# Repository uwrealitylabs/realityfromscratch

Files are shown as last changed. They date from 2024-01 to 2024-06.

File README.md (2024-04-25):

## Overview

We are building our very own, fully custom VR headset called **Reality from Scratch**.

First, we soldered an inertial measurement unit (IMU) and microcontroller unit (MCU) together, and got real-time motion vector data translated into SteamVR with drivers forked from the OpenVR SDK. Then, the VR Compositor output was routed to our VR displays, which comes with accompanying lenses and a custom 3D-printed housing. In addition to the HMD, we are building Vive Wand-style controllers, which we'll dive into deeper below.

From this headset, we plan to build other systems, such as an inside-out 6DoF tracking solution using visual-inertial odometry, or a varifocal optical stack using eye tracking and motors or voice coils.

<div align="middle">
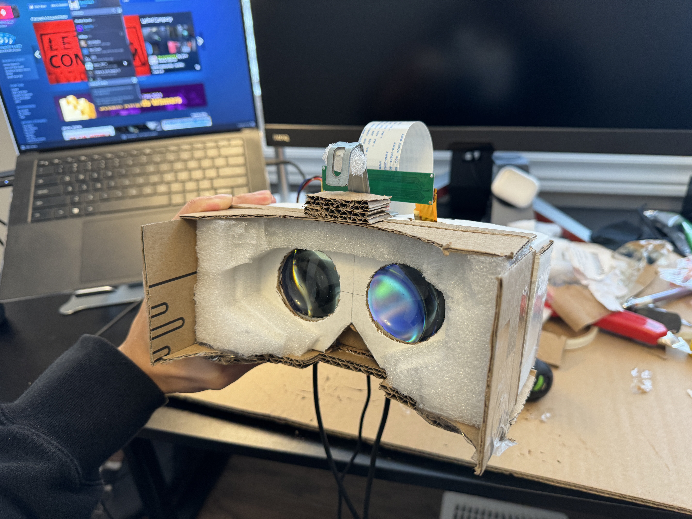
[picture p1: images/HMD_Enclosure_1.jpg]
HMD Enclosure for the HMD
 </div>

### Basic HMD Hardware

| **Components** | **Our Choice** | **Count** |
| --- | --- | --- |
| IMU | MPU-9250 | 1 |
| MCU | Arduino Pro Micro | 1 |
| Display | 1440x1440 90Hz LCDs | 2 |
| Housing | 3D-printed | *varies* |
| Lenses | $⌀=50mm,$ $f = 50mm$, biconvex, glass | 2 |

### 6DoF Tracking Hardware

| **Components** | **Count** |
| --- | --- |
| PS3 Eye Camera | min 1, max 7 |
| HadesVR/PS3 Move Controllers | 2 |
| USB Hubs | *varies* |

Here's a simple flow chart of how the different components of the VR device interact with each other:

<div align="middle">
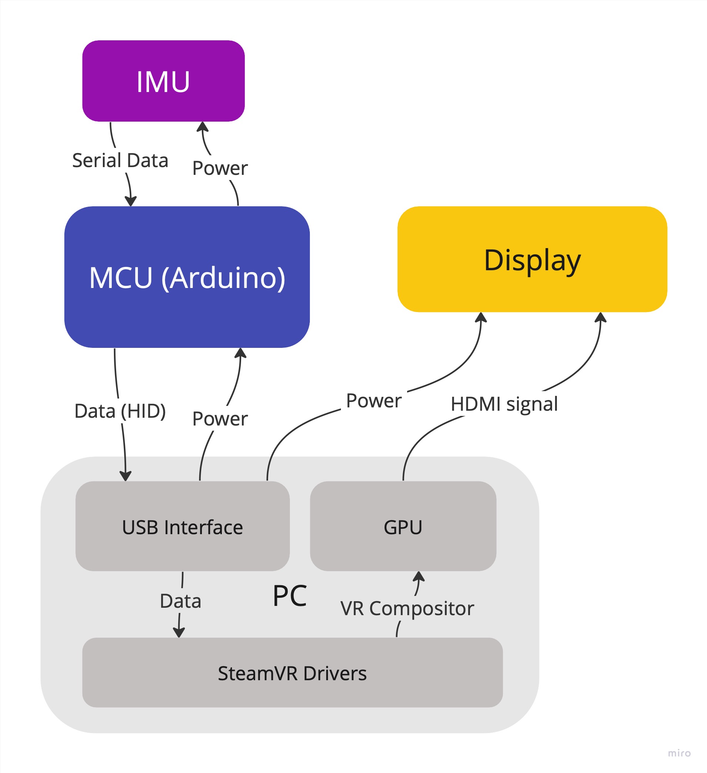
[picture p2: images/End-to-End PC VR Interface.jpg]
End-to-End PC VR Interface
 </div>

### Controllers (coming very soon!)

Our team has received custom PCBs and other various electrical components for the build of 2 DIY Vive Wand-like controllers, which will be based off of [this](https://github.com/HadesVR/Wand-Controller) WIP open-source guide by LiquidCGS (creator of HadesVR). Each controller will have an IMU, a rechargeable battery, RF transceivers, tactile buttons, triggers, and joysticks. The HMD's microcontroller will also be upgraded and moved onto a central PCB. We are almost done with soldering.

<div align="middle">
Controllers! (unfinished) </div>

### Drivers

SteamVR is the only universal platform with accessible driver SDKs (from Valve's OpenVR). It is an easy choice for an open-source VR project. The drivers for Reality from Scratch can be found [here](https://github.com/uwrealitylabs/openvrdriver/tree/main). We use them in conjunction with the FastIMU Arduino library.

### Lenses

We recommend [fresnel](https://xinreality.com/wiki/Fresnel_lens) lenses for any DIY VR build, since they are readily available for very low prices on platforms like Amazon and Aliexpress, and are thin and lightweight. Traditional biconvex lenses are wider, heavier (when built with glass), and usually cost more, but they may have increased visual clarity and no god rays. This is due to the design of fresnels and their fine concentric lines, which can introduce god rays and other distracting artifacts. Below is a visual comparision that should help explain the design of fresnel lenses further.

<p align="middle">
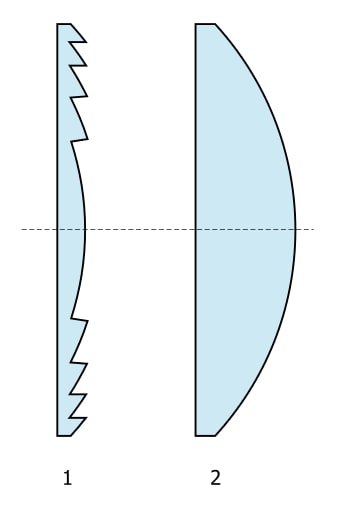
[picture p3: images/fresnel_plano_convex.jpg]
Fresnel and equivalent plano-convex lens.
  
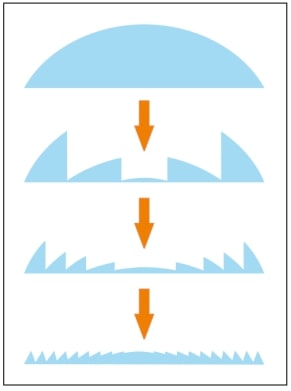
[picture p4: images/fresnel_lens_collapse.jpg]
Collapsing a conventional lens into an equivalent power Fresnel lens.
  
  <br>
  <caption><em>Figure 1 (left): Fresnel lens (left) and equivalent power plano-convex lens (right).</em></caption>
    <br>
  <caption><em>Figure 2 (right): Collapsing a conventional lens into an equivalent power Fresnel lens.</em></caption>
</p>

Outside of biconvex and fresnel lenses, there are not many options, though there are some advanced [DIY stacked lens](https://hackaday.io/project/187343-easy-pancake-lenses) solutions out in the wild.

A lot of these simpler lenses can be purchased at a wide assortment of focal lengths; we hope to test multiple. Depending on the focal length, the length of the headset's housing will vary, so there may be some merit in seeing the difference between shorter and longer housings (in terms of image quality, FOV, perceived weight of the HMD and how this affects comfort, etc.) Creating the mechanical design for the housing of the VR headset will be challenging, given that we'd like to include user-addressable IPD, as well as test different housing for different lenses. However, we are very excited to begin testing this once we finish modelling the 3D prints for our headset.

## Building your own Reality from Scratch

For a comphrehensive guide on how to build your own Reality from Scratch - our open-source, DIY HMD, check out the guide [here](https://github.com/uwrealitylabs/realityfromscratch/blob/main/Guide.md), or join the UW Reality Labs team if you're a student at the University of Waterloo!

<div align="middle">
unfinished HMD module built on HadesVR PCB
<br>
<caption><em>work-in-progress HMD module built on HadesVR PCB.</em></caption>
    </div>
    <br>

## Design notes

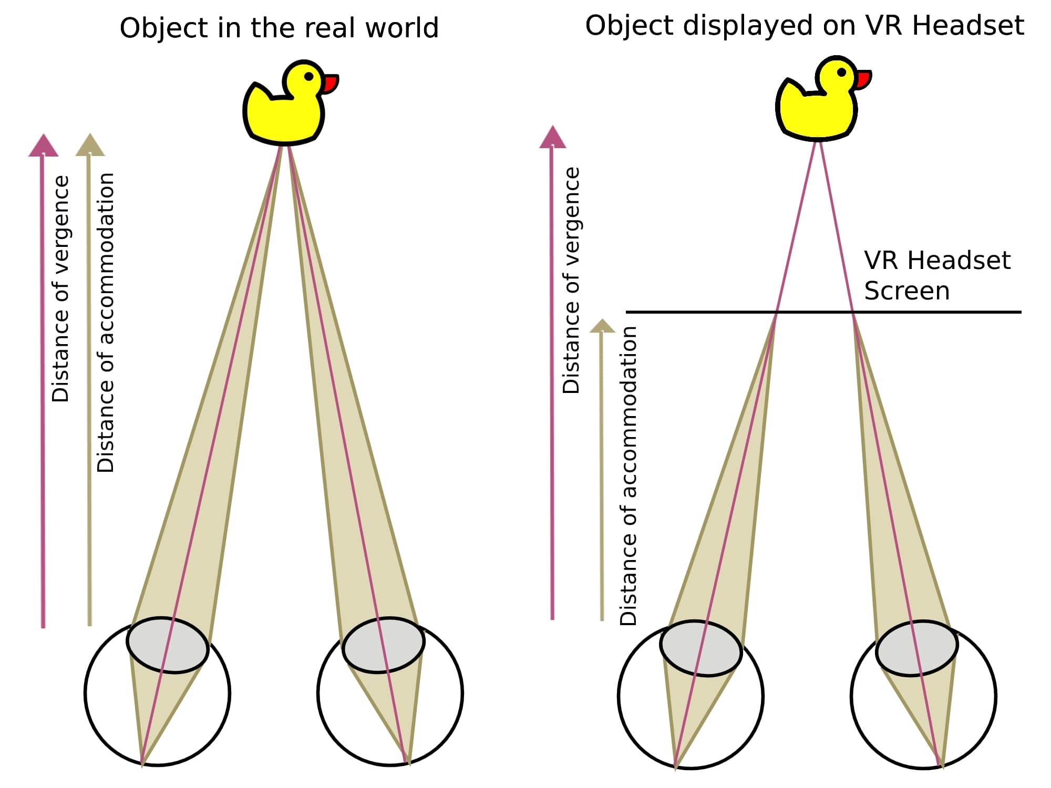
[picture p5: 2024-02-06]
images/Vergence-Accommodation_Conflict_Diagram.jpg

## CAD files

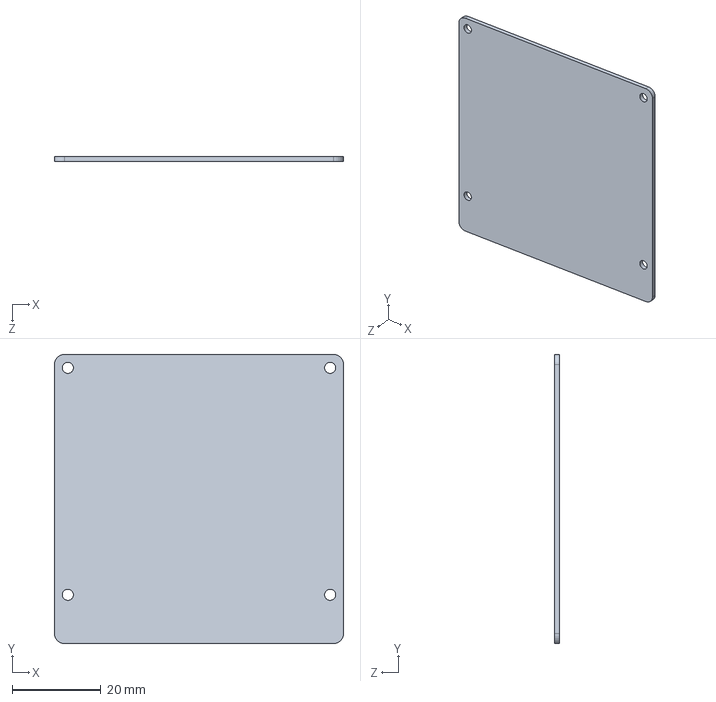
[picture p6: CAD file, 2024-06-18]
mechanical/display_controller.SLDPRT
65.0 x 65.0 x 1.20 mm

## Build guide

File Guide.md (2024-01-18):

# Building Reality from Scratch

Here's a guide on how to build the Reality from Scratch HMD and controllers with 6DoF tracking. This guide is heavily based off of Relativty and HadesVR's guides, with an emphasis on being beginner-friendly.

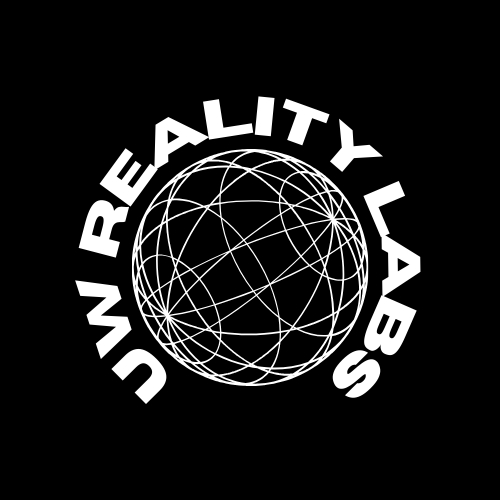
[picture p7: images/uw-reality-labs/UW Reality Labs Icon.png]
UW Reality Labs Icon


## Building the Basic HMD

### Materials

| **Component Type** | **Recommended Part** | **Count** |
| --- | --- | --- |
| IMU | MPU-9250 | 1 |
| MCU | Arduino Pro Micro | 1 |
| Display | 1440x1440 90Hz 2.9" LCDs | 2 |
| Housing | 3D-printed (coming soon) | *varies* |
| Lenses | Fresnel lenses | 2 |

So, a little on our recommendations:

### IMUs and MCUs

The Arduino Pro Micro is a good choice since it supports USB HID. The USB HID class is generally more optimized for smaller, more frequent packets of data vs. serial, which is better for our use since we'll be sending small but very frequent data from our IMU. Other devices, like the Pro Mini and UNO, all use the serial class, which isn't optimal, as we mentioned.

In terms of IMUs; While [FastIMU](https://github.com/LiquidCGS/FastIMU) (what we'll be using to read IMU data) supports the MPU-6050 (which is cheaper), it doesn't include a magnetometer, which could negatively affect overall tracking quality. Given that the MPU-9250 is nearly the same price on AliExpress and Amazon, we figure most people can just purchase the better IMU.

When building Reality from Scratch, we reccommend buying the IMU/MCU first and testing SteamVR output with your monitor's display before buying any more expensive components (for testing purposes). We'll get into the build procedure further down below.

### Displays

In terms of displays, there are two popular options individuals often end up purchasing on AliExpress. This one [(1)](https://www.aliexpress.com/item/1005003041935114.html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) is what we picked. It is one of the cheapest displays on the market that has a respectable resolution (1440x1440, akin to a Valve Index) and a refresh rate at 90Hz (unlike the Index's 120Hz).

<div>
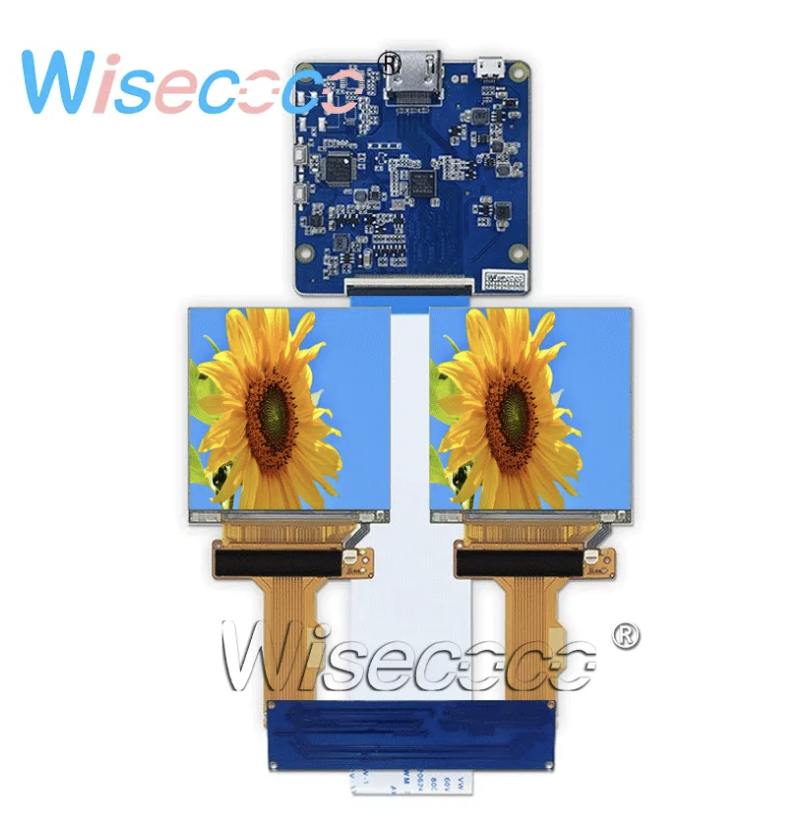
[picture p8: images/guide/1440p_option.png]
1440p display option
 <br>
<figcaption><em>Here's what the listing image for this one looks like, complete with the driver board and 2 displays. Usually sells for ~$150 CAD.</em></figcaption>
    </div>
    <br>

<div>
dual displays for VR <br>
<figcaption><em>Here's what it looks like in person.</em></figcaption>
    </div>
    <br>

This one [(2)](https://www.aliexpress.com/item/32979565265.html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) is a slightly more expensive but also great option that brings OLED to your HMD, meaning better contrast and true blacks. It is at a slightly lower resolution however, coming in at 1080x1200, and it is 3.81 inches (versus the 2.9 inch 1440p display from the first option), bringing its effective sharpness even lower. It does still have 90Hz, though. The specifications are overall very similar to the Oculus CV1's.

<div>
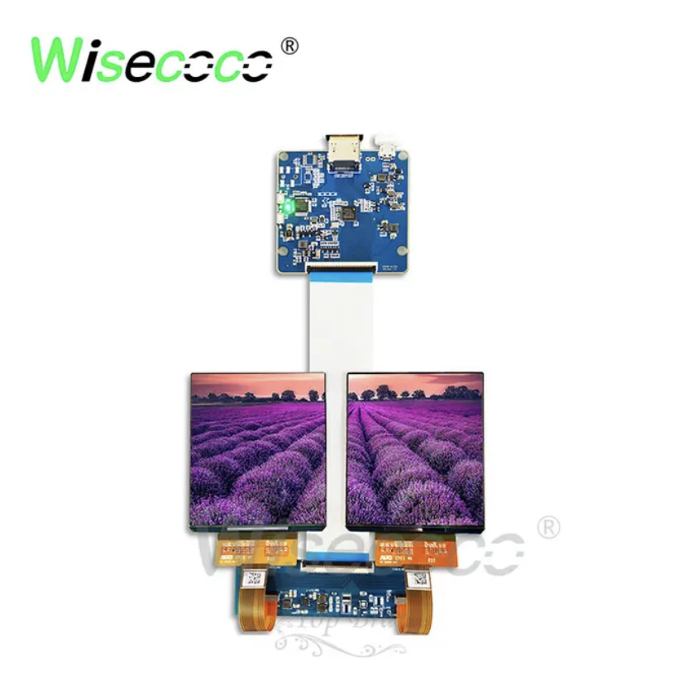
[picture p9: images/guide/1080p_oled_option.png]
1080p OLED display option
 <br>
<figcaption><em>Here's what the listing for the OLED one looks like, with the driver board and 2 displays. This is usually around ~$220 CAD.</em></figcaption>
    </div>
    <br>

The folks over at Smart Prototyping also have a 1440x1600 120Hz display built for Project Northstar (an open-source AR device), which oftentimes can be found for cheaper through B-stock options. Find them [here](https://www.smart-prototyping.com/AR-VR-MR-XR/Display-for-Project-North-Star-3_5inch-1440x1600-pixels%20Promotion%20sale).

You can, of course, purchase any other displays and configure them to your liking. That's what DIY gets you. Just make sure that when purchasing any of these displays, you (1) **purchase both screens and the driver board**, you (2) make sure the driver board has the displays **extend and not duplicate**, and you (3) also **purchase a long, compatible HDMI 2.1 cable and a USB Micro-B to A (or C) cable** for the Arduino. These two cables will be thethering you to your computer, so make sure they're of decent quality as well (watching for durability/flexibility).

### Lenses

In terms of lenses, PMMA plastic (acrylic) fresnels are the easy pick. They are absolutely everywhere, are cheap, and are lighter/more compact than traditional biconvex glass lenses. Since they are everywhere, you can pick a diameter and focal length that you want, and design your housing around those dimensions.

We went with 50mm focal length and 50mm diameter lenses, and they are what our 3D printed design is based around. You could also very well purchase a phone VR kit from Amazon or similar and put in your displays - that would work fine, but you would not know exactly what kind of lenses you are getting. However, some more expensive phone VR models have built-in IPD adjustment, which is very useful.

If you would like to use our 3D printed design, make sure you are using 50mm diameter / 50mm focal length lenses, preferrably biconvex glass (as these are what we designed the housing around, and are thicker than equivalent fresnel lenses). You can find the print design to download in the /prints/ folder (coming very soon).

## Build Guide

We can begin by building out the brains of the HMD. This will take no time and be useful to test the drivers, MCU, and IMU before purchasing and/or putting everything else together. This begins by taking your Arduino Pro Micro and connecting the following 4 pins from your Pro Micro to your IMU using wires to connect to soldered pins, or a breadboard:

> GND $\longleftrightarrow$ GND (Ground) <br>
> VCC $\longleftrightarrow$ VCC (Voltage) <br>
> SDA $\longleftrightarrow$ SDA (Serial Data) <br>
> SCL $\longleftrightarrow$ SCL (Serial Clock) <br>

Arduino Pro Micro Pinout (SparkFun)
<br>

<em>Example SparkFun Arduino Pro Micro Pinout. GND, VCC, SDA, and SCL must be connected.</em><br>

We can now upload the FastIMU firmware to the Arduino Pro Micro. To do this, download/open the Arduino IDE on your PC and connect your Pro Micro using your USB cable. Next, we need to select our board from the dropdown menu located at the top of the IDE.

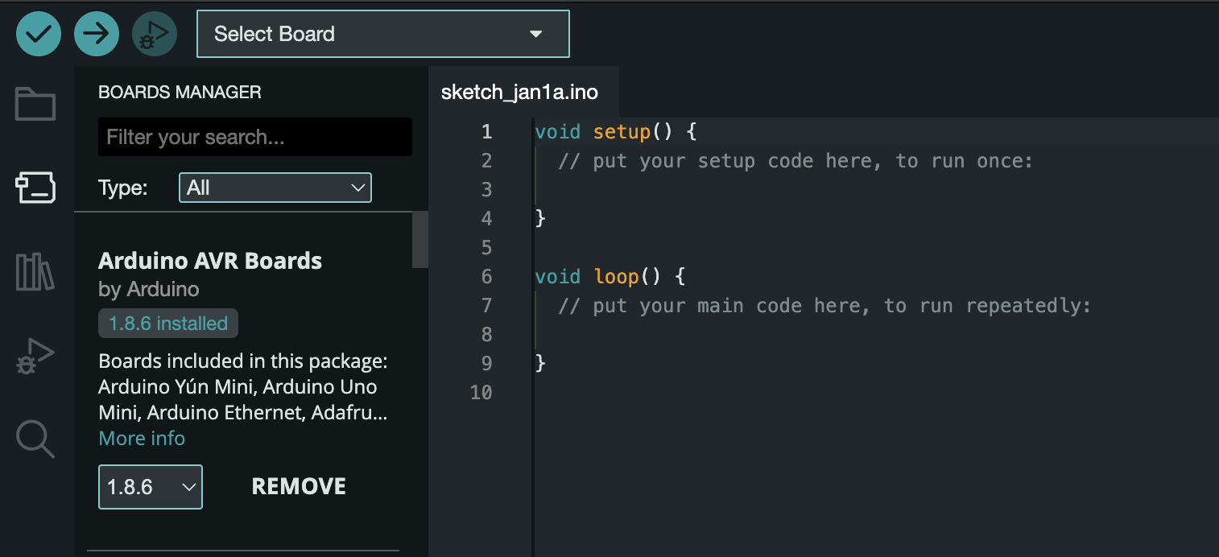
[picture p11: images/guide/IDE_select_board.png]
'Select Board' in the Arduino IDE


<em>'Select Board' in the Arduino IDE.</em><br>

The exact model name of your MCU varies depending on your board. Some boards will be recognized as a 'Pro Micro' or an 'Arduino Leonardo', but our Arduino Pro Micro was a SparkFun derivative, so we installed the [SparkFun board library](https://learn.sparkfun.com/tutorials/installing-arduino-ide/board-add-ons-with-arduino-board-manager) and found the SparkFun Pro Micro in the dropdown menu.

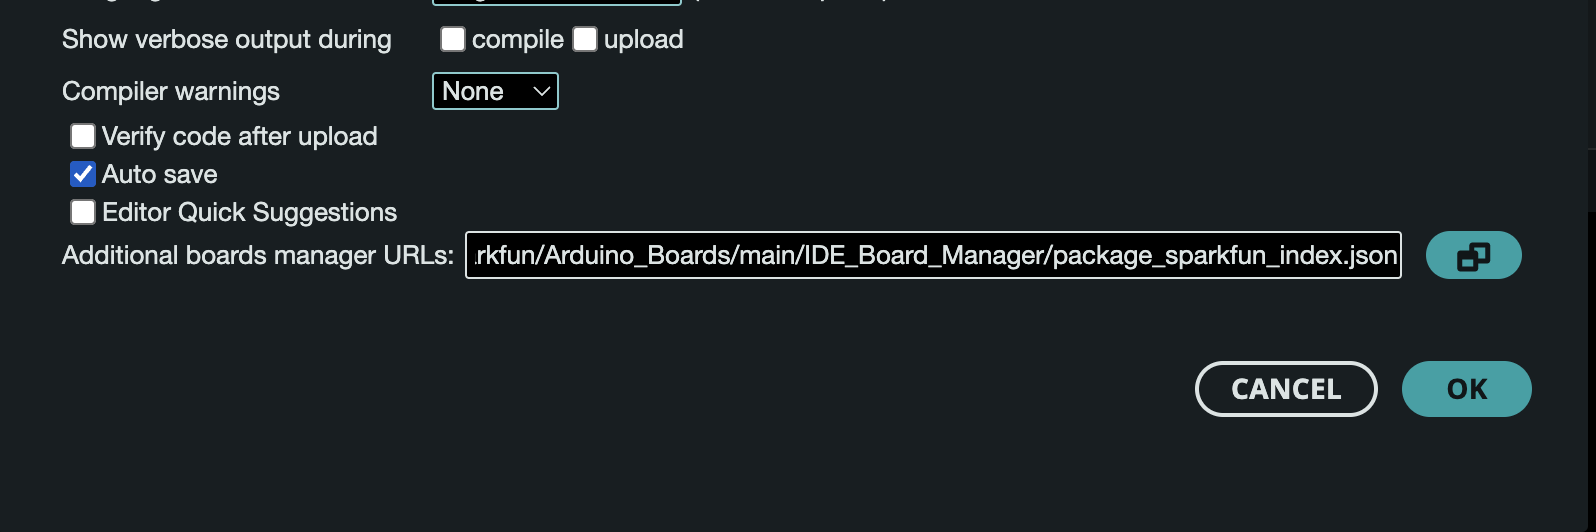
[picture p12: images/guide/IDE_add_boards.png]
Add additional boards in the Arduino IDE


<em>Installing SparkFun boards: Copy and Paste SparkFun boards URL into 'Additional board manager URLs' (Arduino IDE -> Settings)</em><br>

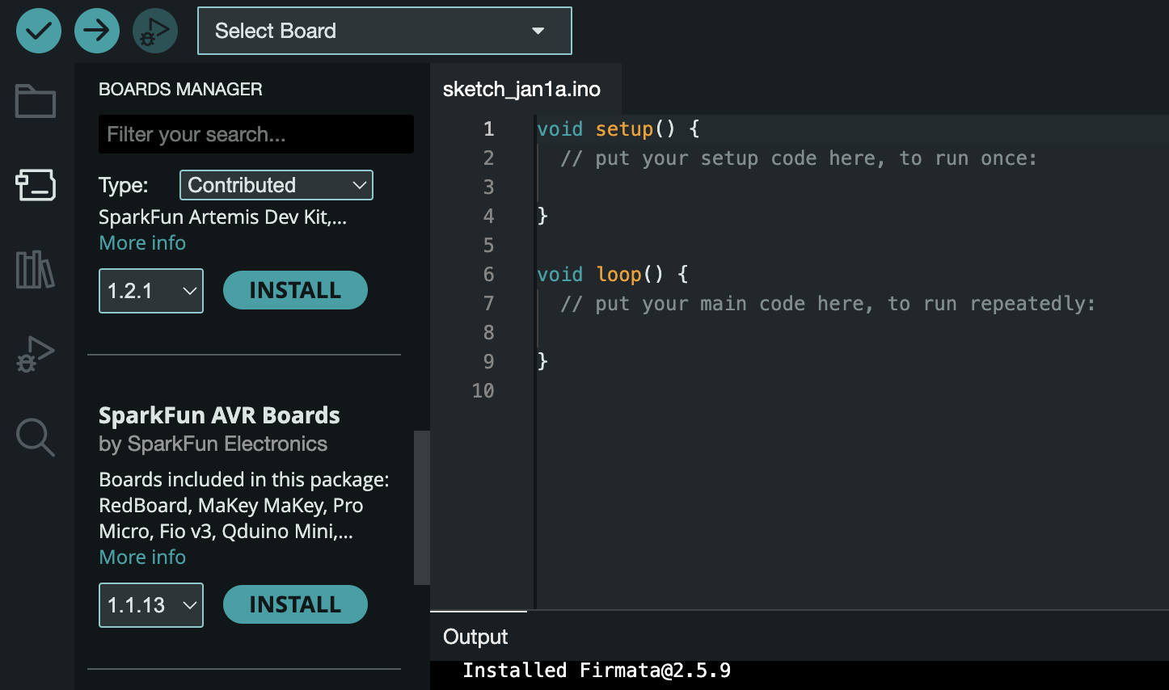
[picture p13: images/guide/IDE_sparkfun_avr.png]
Install SparkFun AVR Boards


<em>Sort by Type: Contributed in Boards Manager and install 'SparkFun AVR Boards'.</em><br>

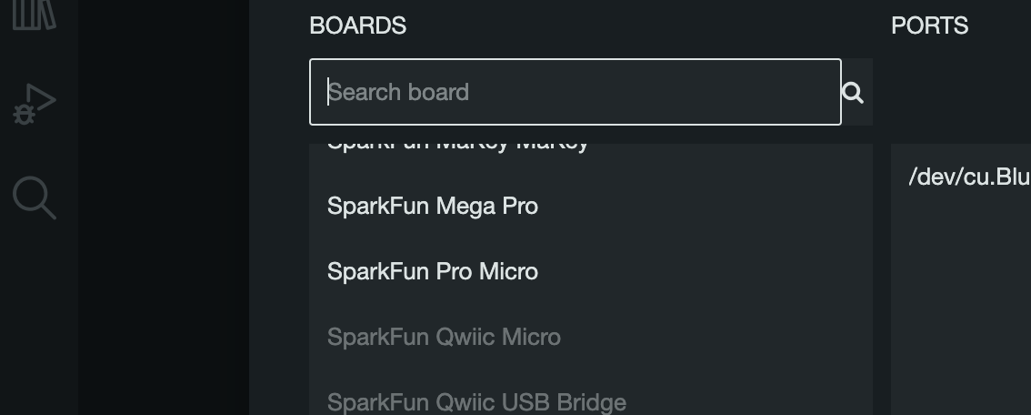
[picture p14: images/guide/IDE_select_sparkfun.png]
Select SparkFun Pro Micro in the IDE


<em>You can now select the SparkFun Pro Micro in the Arduino IDE.</em><br>

This should hopefully have your IDE connected to your Arduino board - but you might want to upload an example sketch to make sure everything is working fine. For our SparkFun Pro Micro derivative board, we had to set the operating voltage to 5V and microcontroller to run at 16MHz first before doing anything else.

Given that, you are now ready to upload the FastIMU firmware.

In order to upload the firmware, you will need the [FastIMU](https://github.com/LiquidCGS/FastIMU/tree/main) library (and the RF24 Arduino Library if you're using HadesVR's HMD PCB with the RF transcievers). You can download these through the Library Manager on the Arduino IDE. 

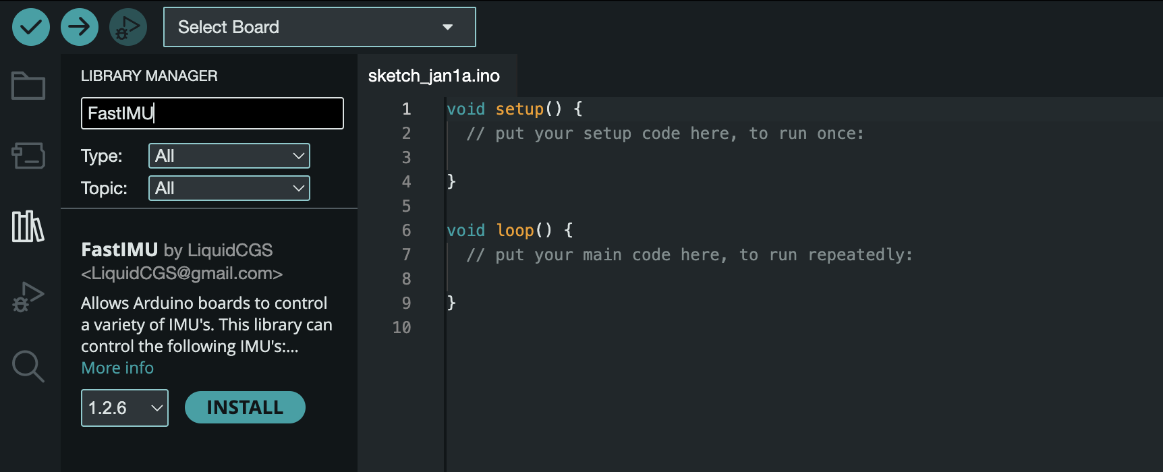
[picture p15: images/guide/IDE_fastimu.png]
FastIMU Download


<em>Search for and download the FastIMU library in the library manager.</em><br>

This will have added the example sketches we need. Upload the "Calibrated_HadesVR" or "Calibrated_Relativty" sketch to the Arduino Pro Micro. Calibrate your IMU by following the steps shown in the console.

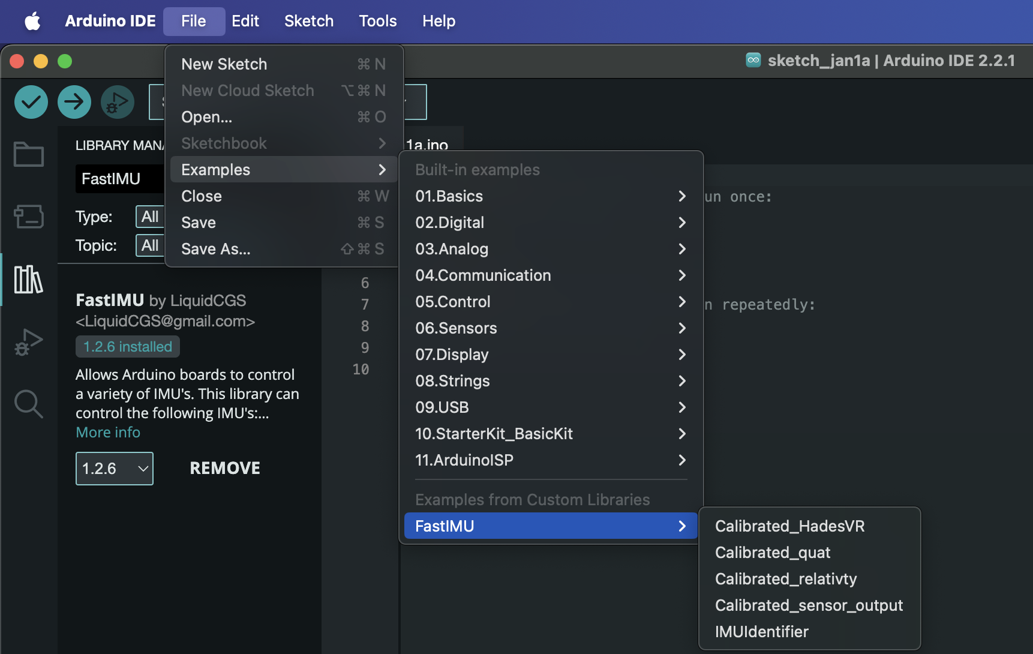
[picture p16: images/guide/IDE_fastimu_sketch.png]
FastIMU Example Sketches


<em>This is where you can find the example sketches.</em><br>

The next step is to allow for your MCU to send data to SteamVR through the drivers. Install the Reality from Scratch drivers by placing the "realityfromscratch" drivers (which you can download [here](/drivers/)) within the SteamVR "drivers" folder (usually located at C:\Program Files (x86)\Steam\steamapps\common\SteamVR\drivers).

Next, open the configuration file (called 'default.vrsettings') for the SteamVR driver - we're going to add the USB PID and VID values of your MCU (as set by Arduino sketch) to the drivers. Make sure the following values are set as such in the file if you uploaded the "Calibrated_Relativty" sketch:

      "hmdPid" : 32823,
      "hmdVid": 9025,

Or if you used the "Calibrated_HadesVR" sketch, make sure they are set as such (our drivers are set to this by default):

      "hmdPid" : 32822,
      "hmdVid": 9025,

If SteamVR fails to pick up your MCU, make sure of your MCU's USB PID and VID values by going into Arduino IDE and selecting Tools -> Get Board Info. This will show your board's PID and VID values in hexadecimal format, so convert them into decimal form and replace the "hmdPid" and "hmdVid" values as needed.

Do not delete any of the commas. Make sure the following is set to false as well:

      "hmdIMUdmpPackets":  false,

If "hmdIMUdmpPackets" is left as 'true', your SteamVR output will go haywire, as the driver will dump random numbers in place of real data from the IMU.

The last thing left to do in the file is to configure your display settings.
